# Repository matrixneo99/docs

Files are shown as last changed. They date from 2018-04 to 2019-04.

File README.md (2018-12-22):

# AWTRIX 2.0

After a break of more than half a year the development of ***AWTRIX 2.0** started.
The reason for a complete version jump is relatively simple:
The ESP8266 is very inflexible for such applications. This is partly due to the relatively low memory and RAM. It was simply not possible to add more functions and at the same time guarantee the stability or to keep features like OTA.

***AWTRIX 2.0*** is therefore built in 2 parts:
The ESP8266 as Matrix Driver (AWTRIXController)
And a Java capable host like Windows, MacOS, RaspberryPi, etc. The host takes over the complete logic while the ESP takes over the commands and displays them stubbornly.

***AWTRIX 2.0*** is based on Java 8 and has been trimmed for resource-saving functionality.
(5% CPU Load on a Rpi ZeroW).

Due to the inexhaustible resources I was able to make ***AWTRIX 2.0*** a great user experience. It starts with the simple setup and installation and ends with the intuitive operation. ***AWTRIX 2.0*** is the result of one month of hard work and very good feedback from the community.

Features of ***AWTRIX 2.0***:
- Platform independent
- Control via web interface with responsive Design
- Apps can be added through the integrated Appstore.
- Felxible App management
- Support for Community Apps
- API interfaces like MQTT and REST

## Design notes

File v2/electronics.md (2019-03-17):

# **Electronic**

The electronics can either be soldered to a breadboard or wired "overhung". (PCB may still be available for a small fee in the future)

Soldering directly to the matrix can have fatal consequences, as the flexible PCB and especially the LEDs are extremely heat-sensitive. Leave the cable at the input (DI,5V,GND) and cut off only the plug. If your matrix has an output (DO), you can remove it completely.
Before soldering the socket for the power supply, screw it to the housing with 2 soldered wires.

***Core setp up:***   
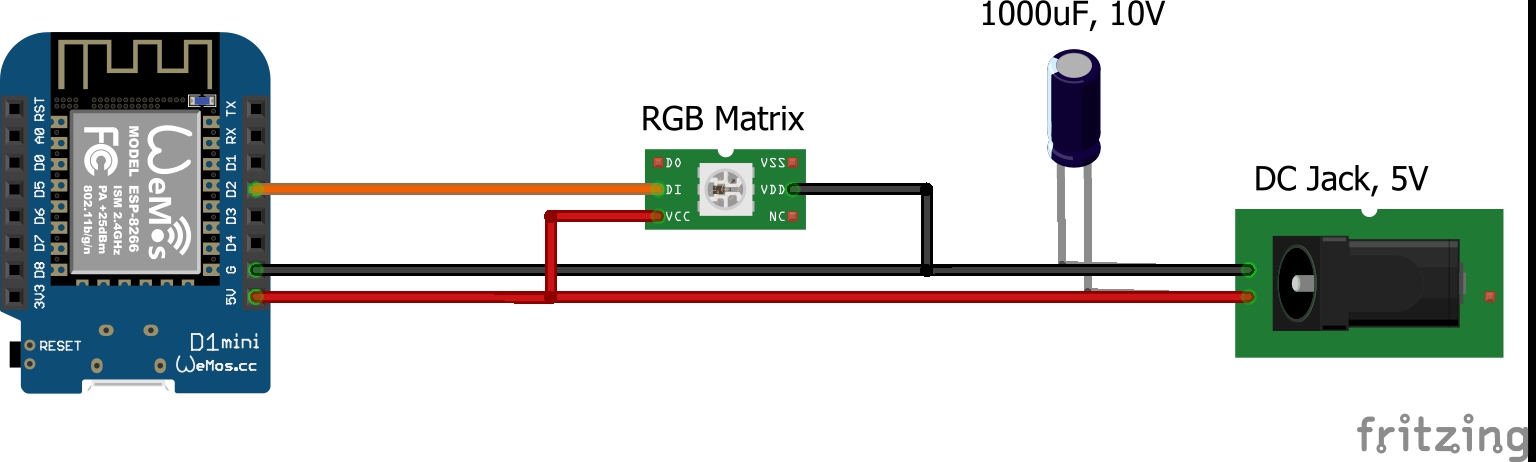
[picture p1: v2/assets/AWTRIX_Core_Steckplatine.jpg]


***Optional LDR setp up:***  
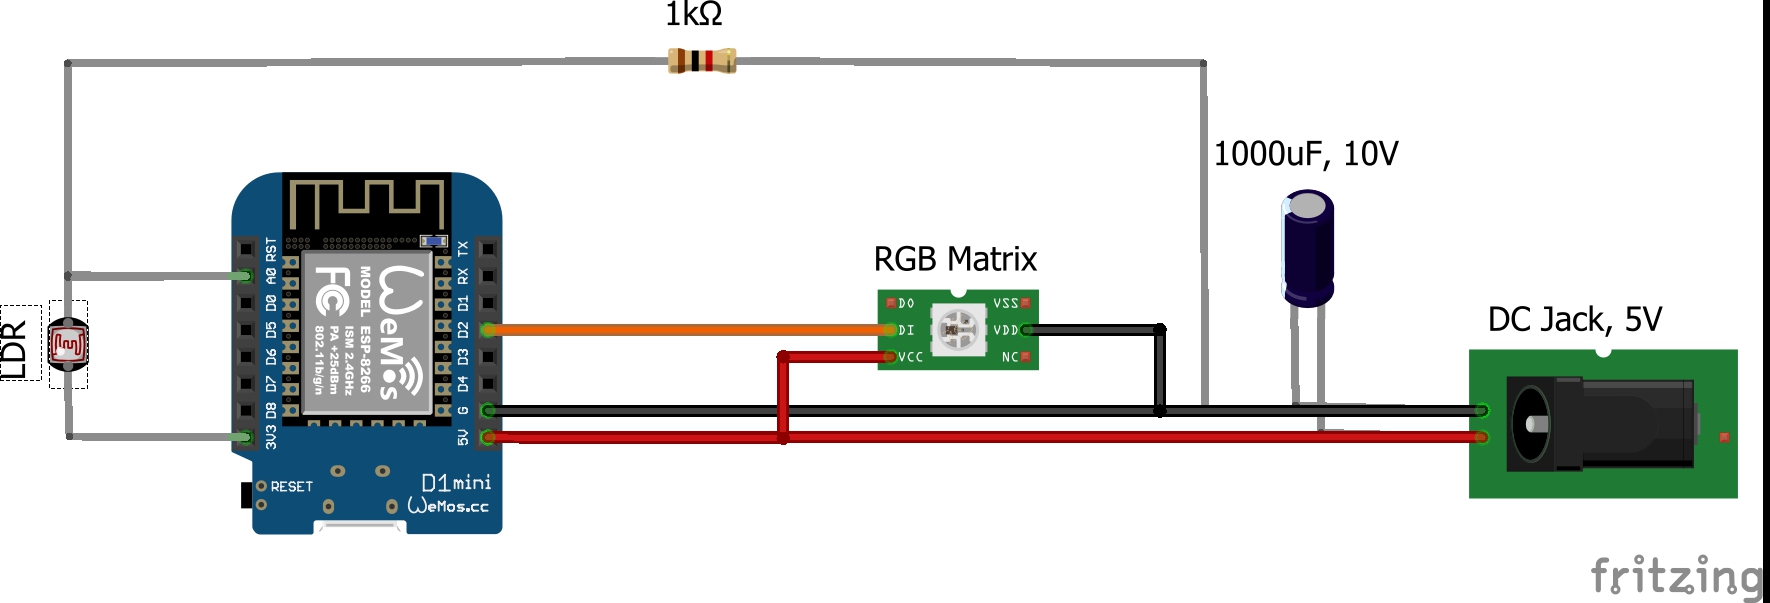
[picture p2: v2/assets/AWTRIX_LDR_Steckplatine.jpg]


***Optional Gesture setp up:***  
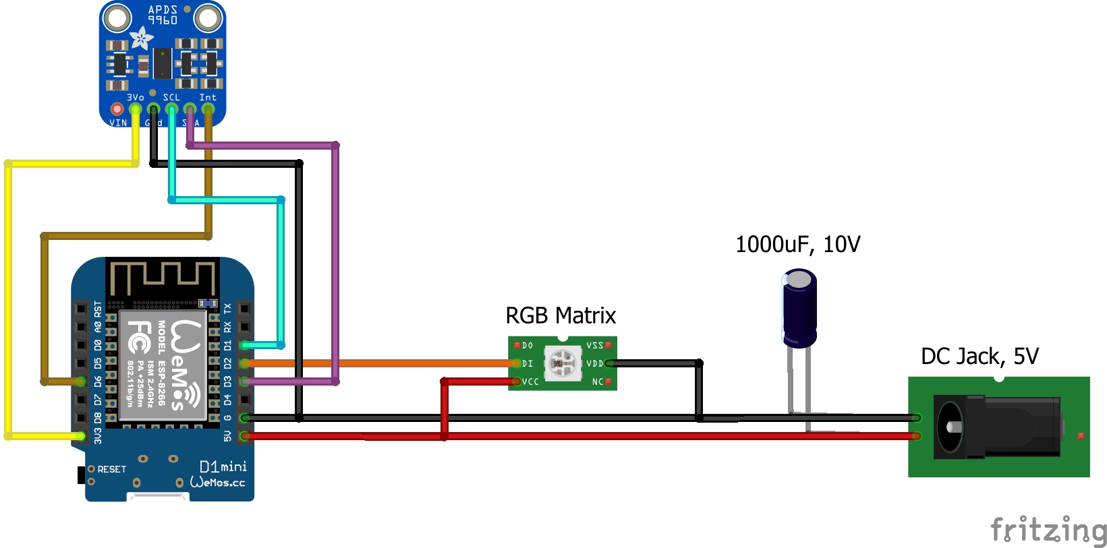
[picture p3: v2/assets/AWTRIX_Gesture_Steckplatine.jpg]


***Gesture control*** 
You can control AWTRIX with Hand gestures (Only switching between Apps for now) with a APDS-9960 Gesture Sensor
Please keep in mind that the Housing is not prepared for mounting this sensor. You will have to do it by your own.
  
!> IMPORTANT: The APDS-9960 can only accept 3.3V!

| Wemos | APDS-9960 | Function |
| --- | --- | --- |
|3.3V|VCC|Power|
|GND|GND|Ground|
|D3|SDA|I2C Data|
|D1|SCL|I2C Clock|
|D6|INT|Interrupt|

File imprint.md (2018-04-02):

# **Housing**

## **3D-Print**

The housing can be created with a 3D printer. The necessary files can be downloaded from Thingyverse.[https://www.thingiverse.com/thing:2791276](https://www.thingiverse.com/thing:2791276)

The 3D objects are already aligned as they should be printed to require as little support material as possible. Please print the **LED grid in black**, otherwise the "pixels" are not clearly separated, as they shine through the material.
**Recommended print settings:**

* 0.2 mm layer resolution

* 20% infill

* Support from the bed

* 45-55 mm/s

## **Assembly**

First of all, glue the 2 parts for the LED Grid together on the inside.
As a diffuser I used high quality and thicker paper - it’s important that you don’t see the fibres when you hold it against bright light like normal printer paper.
Then smear the flat side of the LED grid with glue stick and glue the paper onto it.
this is best done where Awtrix will end up. Due to high temperature and humidity fluctuations, the paper can warp slightly.
Then put the 2 housings parts together and, if necessary, fix it with a little glue. Solder 2 cables to the power jack and screw it to the housing. You can then continue directly with the remaining wiring. the LDR can be plugged through one of the upper 5mm ventilation holes. When everything is ready, place the diffuser facing down and place the LED matrix on top of it, which should fit perfectly in the groove and Press the housing onto the LED Grid. Then turn everything on the back and attach the front frame.

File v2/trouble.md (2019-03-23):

## **Troubleshooting**

### Firmware
If you have trouble to compile the Firmware, try updateing platformio via the terminal  
```platformio update```   

![image alt text](assets/plattformio_update.jpg)  

### Matrix
If your Matrix shows weird Pixel and you cant read it, you have to set the Matrixmode 2 and flash the Firmware again. 
- just uncomment (remove the first two //) 
```//#define MATRIX_MODEV2```

### Jittering display
 
AWTRIX sends the frames to the ESP with an average of 15 FPS (this depends on the current App).
If the Wifi Router does not pass the frames to the ESP in real time, the display jerks. There is no Framebuffer in the ESP firmware.
It is important to keep the network connection as short as possible. If possible, connect the server via network cable and avoid using Wifi repeaters or Powerlan adpater. These can delay the communication.

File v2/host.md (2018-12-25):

AWTRIX 2.0 can run on any platform (Windows, MacOS, Linux), the only requirement is the support of Java8. It is a non-GUI application so you doesnt need an desktop enviroment.   
This Tutorial describes the installation on a Linux machine (in my case a Raspberry ZeroW with Rasbian Lite)

First check if Java is installed  
```java -version```  
  
Otherwise install the latest Java8:  
```sudo apt-get install oracle-java8-jdk```  

Set your timezone: e.g  
``` sudo timedatectl set-timezone Europe/Berlin```  
   
## **Quickstart**
This short example shows how to start the Java application.
Move to the next point for installing on a Linux machine such RaspberryPi

Download the current java  file
[AWTRIX Java application](http://awtrix.blueforcer.de/awtrix.jar)

 and start it via command line or terminal
 ``` sudo java -jar awtrix.jar ```    

!> **sudo** is not always needed. It depends on the folder in wich you want to start the Application. Awtrix need to create new folders and files, so in few cases Awtrix has no write permissions.

Shortly after the start the web interface can be called via http://awtrix_ip:7000.

## **Installing on a Linux machine with Autostart**
```sudo mkdir /usr/local/awtrix```  
```cd /usr/local/awtrix```    
```sudo wget http://awtrix.blueforcer.de/awtrix.jar```

### **Autostart**

Create a file under  **/etc/systemd/system/** with nano or vi. eg.  
```sudo nano /etc/systemd/system/awtrix.service```  
  
Paste the code below in this new file:
```
[Unit]
Description = AWTRIX Service
After network.target = awtrix.service

[Service]
Type = forking
WorkingDirectory =/usr/local/awtrix
ExecStart = /usr/local/bin/awtrix.sh start
ExecStop = /usr/local/bin/awtrix.sh stop
ExecReload = /usr/local/bin/awtrix.sh reload

[Install]
WantedBy=multi-user.target
```

Create a new file under ***/usr/local/bin/*** eg.   
```sudo nano /usr/local/bin/awtrix.sh```  
  
And paste this code
```
#!/bin/sh
SERVICE_NAME=awtrix
PATH_TO_JAR=/usr/local/awtrix/awtrix.jar
PID_PATH_NAME=/tmp/awtrix-pid
case $1 in
    start)
        echo "Starting $SERVICE_NAME ..."
        if [ ! -f $PID_PATH_NAME ]; then
            sudo nohup java -jar $PATH_TO_JAR /tmp 2>> /dev/null >> /dev/null &
                        echo $! > $PID_PATH_NAME
            echo "$SERVICE_NAME started ..."
        else
            echo "$SERVICE_NAME is already running ..."
        fi
    ;;
    stop)
        if [ -f $PID_PATH_NAME ]; then
            PID=$(cat $PID_PATH_NAME);
            echo "$SERVICE_NAME stoping ..."
            kill $PID;
            echo "$SERVICE_NAME stopped ..."
            rm $PID_PATH_NAME
        else
            echo "$SERVICE_NAME is not running ..."
        fi
    ;;
    restart)
        if [ -f $PID_PATH_NAME ]; then
            PID=$(cat $PID_PATH_NAME);
            echo "$SERVICE_NAME stopping ...";
            kill $PID;
            echo "$SERVICE_NAME stopped ...";
            rm $PID_PATH_NAME
            echo "$SERVICE_NAME starting ..."
            sudo nohup java -jar $PATH_TO_JAR /tmp 2>> /dev/null >> /dev/null &
                        echo $! > $PID_PATH_NAME
            echo "$SERVICE_NAME started ..."
        else
            echo "$SERVICE_NAME is not running ..."
        fi
    ;;
esac
```

save the file and give execution permisions

``` sudo chmod +x /usr/local/bin/awtrix.sh``` 

Test that it runs with:  
```sudo /usr/local/bin/./awtrix.sh start```     
Test that it stops with:   
```sudo /usr/local/bin/./awtrix.sh stop```     
Test that it restarts with:  
```sudo /usr/local/bin/./awtrix.sh restart```     

If everything is working, enable the service with the command

```sudo systemctl enable awtrix```  

To run awtrix  
```sudo systemctl start awtrix.service ```   
To stop awtrix   
```sudo systemctl stop awtrix.service```   
To restart awtrix   
```sudo systemctl restart awtrix.service``` 

## **Docker**
**(Only for x64 platforms!)**  

https://hub.docker.com/r/o0shojo0o/awtrix

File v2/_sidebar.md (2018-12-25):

* [Home](v2/)

* Hardware
    * [Partslist](v2/partslist)
    * [Electronics](v2/electronics)
    * [Housing](v2/housing)

* Software
    * [AWTRIX Controller](v2/firmware)
    * [AWTRIX Host](v2/host)

* Usage
    * [Webinterface](v2/web)
    * [Appsetup](v2/appsetup)
    * [API](v2/api)

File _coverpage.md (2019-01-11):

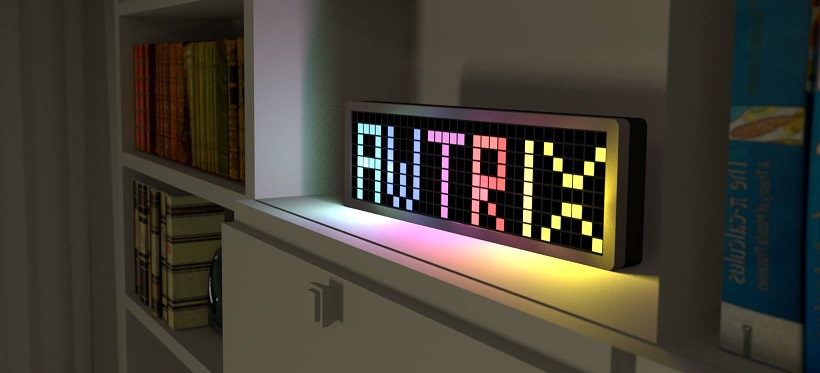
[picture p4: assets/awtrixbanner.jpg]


# AWTRIX 

> Official (BETA) documentation

* Simple to build
* Lots of functions
* Opensource

[Github](https://github.com/awtrix/awtrix)
[Getting Started](v1/README)

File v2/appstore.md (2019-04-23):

## **Appstore**   
AWTRIX has its own appstore.  
Here all tested apps are provided and can be downloaded or updated.  
After a download you find this app in MyApps.  

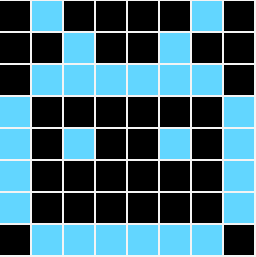
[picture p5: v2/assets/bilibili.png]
 **Bilibili**  
Shows count of fans at Bilibili.  
https://space.bilibili.com  

 **Sunrise**  
Shows sunset and sunrise times for a given location.  
https://www.sunrise-sunset.org 

 **GameOfLife**  
Conway's Game of Life  
Internal App

 **LookingEyes**  
Just some looking eyes :)   
Internal App

 **Matrix**  
Shows the popular Matrix animation.  
Internal App

 **PeopleInSpace**  
Shows how many people are in space right now.     
https://www.howmanypeopleareinspacerightnow.com/ 

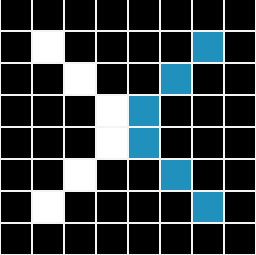
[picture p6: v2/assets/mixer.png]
 **mixer**  
Shows your mixer subscriber count or your live viewers while youre streaming.     
https://mixer.com/  

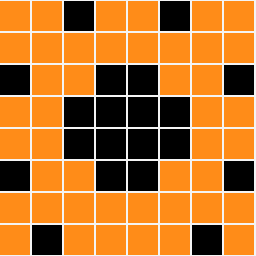
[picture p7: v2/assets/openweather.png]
 **OpenWeather**  
Shows the current temperature of your location.    
https://openweathermap.org/  

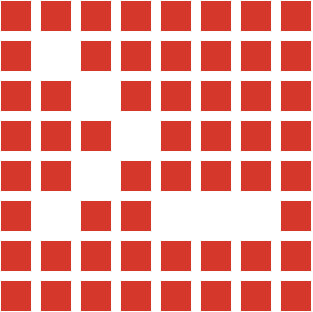
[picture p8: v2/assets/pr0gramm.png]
 **pr0gramm**  
Show the lenght of your Benis.     
https://pr0gramm.com  

 **MinecraftServer**  
Shows the player count of a Minecraft Server.  
Only appears if the server is online.  
https://www.minecraft.net  

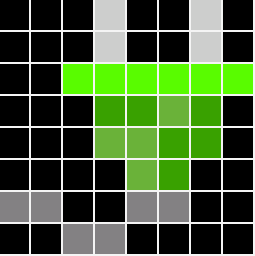
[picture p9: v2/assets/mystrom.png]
 **mystrom**  
Shows the state and power consumption of your MyStrom SmartPlug.  
https://mystrom.com/  

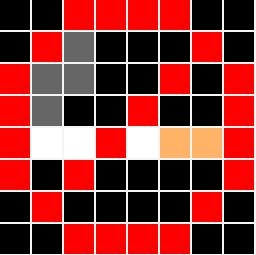
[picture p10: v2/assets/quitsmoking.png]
 **QuitSmoking**  
Shows the days how long you don't smoke anymore.  
Internal App  

 **TronalDump**  
Shows the dumbest things Donald Trump has ever said.  
https://tronalddump.io  

 **Countdown**  
Shows the remaining days from now to a target date.  
Internal App  

 **Crypto**  
Shows prices for any cryptocurrency. Set your desired Coin and your currency.   
https://www.cryptonator.com/api    

 **facebook**  
Shows your Facebooksite likes count.   
www.facebook.com  

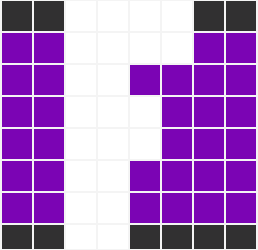
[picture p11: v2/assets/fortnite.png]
 **fortnite**  
Shows your Kills, Wins, Wins% and K/D.   
https://www.epicgames.com/fortnite/de/home  

 **gas**  
Zeigt dir die Spritpreise in deiner Naehe an.(Tankerkoenig API)  
www.tankerkoenig.de  

 **instagram**  
Shows your Instagram follower count.   
www.instagram.com  

 **matomo**  
Shows you the visitors of the transferred Matomo instance who were online during the given time period.  
http://matomo.org  

 **moon**  
Get Today's Moon Phase with current viewing information.  
Internal App  

 **news**  
This app provides live top and breaking headlines for your country.  
http://newsapi.org  

 **octoprint**  
Shows the percentage of progress and remaining time of OctoPrint printing.  
http://octoprint.org  

 **overwatch**  
Shows your current Skillranking.  
http://playoverwatch.com  

 **pinterest**  
Shows your pinterest follower count.  
www.pinterest.com  

 **pm**  
Shows the atmospheric particulate matter (PM).  
https://openaq.org/#/map

 **speedtest**  
Measures the time between the Frames.  
Internal App  

 **twitch**  
Shows your Twitch subscriber count or your live viewers while you are streaming.  
www.twitch.tv  

 **twitter**  
Shows your Twitter Follower count.  
http://twitter.com  

 **weather**  
Shows the current temperature of your location.  
www.apixu.com  

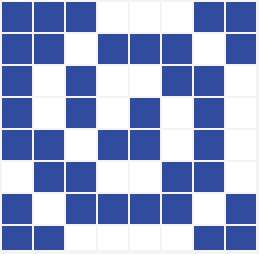
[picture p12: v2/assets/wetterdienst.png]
 **wetterdienst**    
Displays weather-warnings of Deutscher Wetterdienst.  
Only appears if there is at least one warning.  
https://www.dwd.de/DE/leistungen/opendata/help/warnungen/cap_warncellids_csv.csv/

 **youtube**  
Shows your Youtube subscriber count.  
www.youtube.com

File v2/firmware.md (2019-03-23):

## **IDE**

Platform.IO is used to edit and upload the firmware.
The underlying IDE (Atom, Visual Studio Code) does not matter.
However, this manual is based on Visual Studio Code(VSC) and may need to be adapted.
The installation of the IDE is described in the following link:
[https://platformio.org/platformio-ide](https://platformio.org/platformio-ide)

## **Download and open firmware**

The firmware can be downloaded from github as a ZIP file
[https://github.com/awtrix/AWTRIX2.0-Controller](https://github.com/awtrix/AWTRIX2.0-Controller)
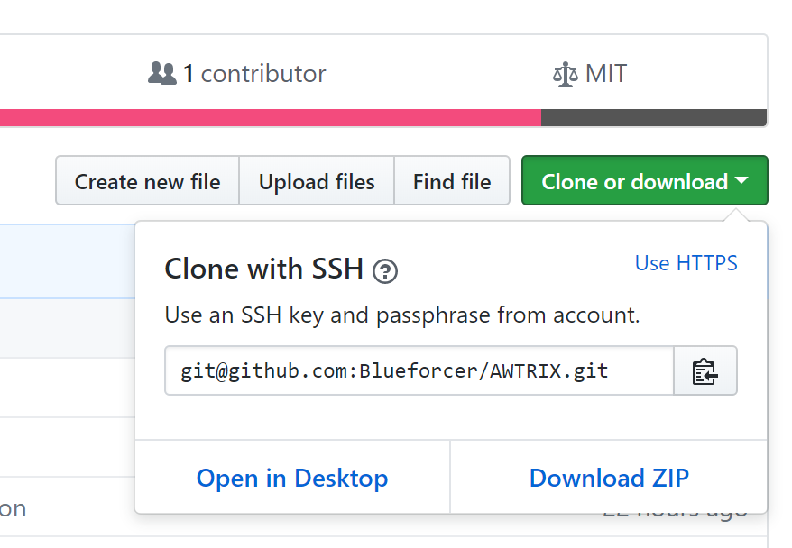
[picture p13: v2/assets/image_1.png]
image alt text


Unzip the ZIP file with a suitable unpacker and open the folder in Visual Studio Code.

## **Setup**

Before flashing the Firmware, open **awtrix-conf.h** and edit your wifi credentials and set the IP from the Server wich should run the serverapplication.  If you using a LDR for automatic brightness control, you also need to modify the LDR section. if not, just ignore it.
If you want to use Gesture Control with the APDS-9960 Sensor, Set GESTURE to true  
image alt text

 Then simply flash the firmware. In VSC, this is done in the blue line at the bottom of the window:  

image alt text

## **OTA(Over the air) Update**
AWTRIXController supports over-the-air updates. PlatformIO Terminal:  
(Replace IP of the AWTRIX controller)  
```platformio run -t upload --upload-port 192.168.178.96```
Please note: First OTA only works after ESP reset  

![image alt text](assets/OTA_update_AWTRIXController.jpg)

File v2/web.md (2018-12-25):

## **Webinterface**

In order to make the operation as simple as possible for everyone, the complete operation takes place via a web interface.
The standard port is 7000.

Here you can manage all your settings, manage your apps and download new one.

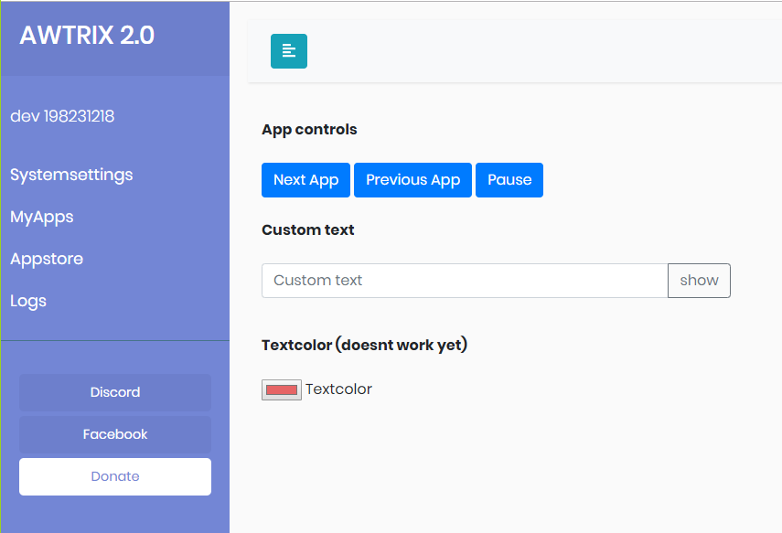
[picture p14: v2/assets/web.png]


## **Systemsettings**
Here you will find all relevant settings concerning the operation of Awtrix. Like e.g. brightness, text color or connection settings

## **MyApps**
The administration of all your apps takes place here.
Here you can configure or delete your apps  
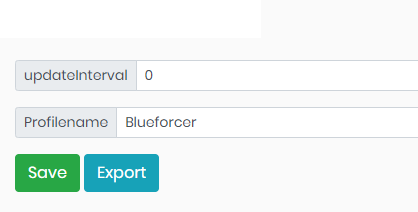
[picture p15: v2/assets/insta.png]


Every App has its own updateInterval. If it is set to 0, it means that this app together with the other apps will be updated after a global period. (Systemsettings->updateInterval).   
This setting is sufficient for most apps not to exhaust the API quota.  
However, if desired, the interval at which the app fetches new data can be forced. Just enter a timespan in seconds (minimum 10s). 

## **Appstore**
Awtrix has its own appstore.
Here all tested apps are provided and can be downloaded or updated.
After a download you find this app in MyApps. New apps are only displayed if they have been set up.

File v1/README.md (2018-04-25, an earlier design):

# AWTRIX

Welcome to my first open source project. This documentation is maintained to the best of my knowledge and belief. However, it can of course happen that errors creep in. If you have any problems or questions, please feel free to contact the Facebook group. They'll be happy to help you.  

Special Thanks to my friend Quentin Daems for this review! [Subscribe](https://www.youtube.com/channel/UCM8iZUKxIHGmAaRcQ_aTYfA) his Channel for more Weekend Makes!  
<iframe width="560" height="315" src="https://www.youtube.com/embed/PjhV3jEGNtc?rel=0" frameborder="0" allow="autoplay; encrypted-media" allowfullscreen></iframe>  

Here are a few links:  
  
[Release Page](https://awtrix.github.io)  
[Facebook Group](https://www.facebook.com/groups/126493104851075/)  
[Buy me a coffee or a case of beer :-)](https://www.paypal.com/donate/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)  

AWTRIX is a smart WiFi-capable clock based on an ESP8266.

- Time and date via NTP server
- Current weather via Openweathermap
- Simulation of a virtual "pet" with different emotions 
- Game of Life 
- Youtube Counter
- Facebook Counter
- Twitter Counter
- DHT Senor reading
- Fire simulation

more functions: 
- Control and configuration via BLYNK, MQTT, UDP or Android App
- Automatic brightness control via LDR
- easy Firmware update via WiFi or Web or Autoupdate

The case is designed in Fusion360 and printed in 3D.
You can get the STL-Files from Thingiverse:
https://www.thingiverse.com/thing:2791276

Facebook-Group:
https://www.facebook.com/groups/126493104851075/

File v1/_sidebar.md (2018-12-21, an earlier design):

* [Home](v1/)
* [How it works](v1/description)
* [API](v1/api)
* [Android App](v1/app)
* [Blynk](v1/blynk)
* [Current Blynk Layout](v1/actual_blynk)

* Hardware
    * [Partslist](v1/partslist)
    * [Electronics](v1/electronics)
    * [Housing](v1/housing)

* Software
    * [Firmware](v1/firmware)
    * [First Configuration](v1/config)
    * [Upload to ESP8266](v1/upload)
    * [First start](v1/first_start)
    * [Update](v1/update)

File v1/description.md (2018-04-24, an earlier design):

## How it works

AWTRIX includes a variety of apps that can display different functions. All activated apps are looped one after the other. The adjustable time in which an app is displayed is the same for each app. Each function can be activated in the settings.json.

**Sleep Mode**

the sleep mode can be activated by setting a time period via blynk or the Settings.json.
During this period Awtrix only displays the time (strongly darkened). 

**Rainbow mode**

When Rainbow mode is on, the set text color is ignored and each text is displayed in rainbow colors.

**Here is an explanation of how each officially available app works:**

**TimeApp**

Displays the current time and date rotationally. The time is synchronized with a time server (NTP) every 3 minutes. The BIG_TIME setting changes the type of display.

In addition, the current day of the week can be displayed at the bottom of the screen. Here 7 strokes are drawn which stand for all 7 weekdays (Monday-Sunday). The current day of the week is displayed in white, while the remaining days are displayed in gray. AWTRIX supports the automatic summer and winter time changeover.

**WeatherApp**

shows the current weather with an icon. Furthermore, the current temperature of the configured location is displayed. The data is downloaded from Openweatermap.

**Pet**

Shows 2 eyes that look and blink randomly in all directions. The displayed emotion changes via the setting PET_MOOD.

**GOL**  
Represents the game of the mathematician [John Horton Conway](https://de.wikipedia.org/wiki/John_Horton_Conway).  
Rules of the game: [https://de.wikipedia.org/wiki/Conways_game_of_life](https://de.wikipedia.org/wiki/Conways_game_of_life)

**FacebookApp**

shows the current likes of a Facebook page.

**YoutubeApp**

shows the number of subscribers to a YouTube channel.

**TwitterApp**

shows the number of followers of a Twitter profile.

**FireApp**

simulates a fire source

**DHTApp**

displays the values of a DHT11 or DHT22 sensor. The display changes between temperature and humidity each time the app is restarted.

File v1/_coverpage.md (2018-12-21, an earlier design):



# AWTRIX <small>0.7</small>

> Official (BETA) documentation

* Simple to build
* Lots of functions
* Opensource

[GitHub](https://github.com/awtrix/awtrix)
[V1.0](README)
[V2.0](README)

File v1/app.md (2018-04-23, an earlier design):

## Android App

I am proud to introduce Awtrix's own app. This makes it a lot easier to configure Awtrix.
The app is still in beta but many features are already covered. The app should be self-explanatory. Through the menu in the upper right corner you can open the settings to configure Awtrix and start the games.
You can download the App from the Android [PlayStore](https://play.google.com/store/apps/details?id=de.awtrix). 
An iOS app may follow in the future.

**Please note:**
The app communicates with Awtrix via UDP. 
The User Datagram Protocol (UDP) is the simplest form of IP data transmission. Data is simply chased off in one direction. UPD does not take care that the data is transmitted without errors. It doesn't even guarantee the arrival of the packages.
This form of data transmission is the fastest and simplest but the ESP8266 is much less busy than with TCP.

Anyway, I try to confirm receipt by replying and send it again if necessary, but now and then it can be that the data is lost.
In addition, it may be that other Awtrix applications have problems downloading their data due to a packet flood (e.g. due to a fast change of the brightness). But  after the next Apploop everything should work again.

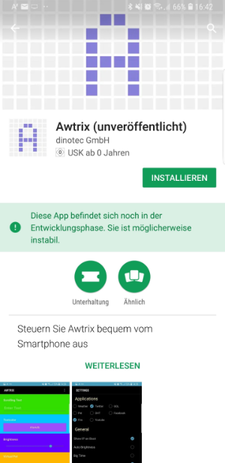
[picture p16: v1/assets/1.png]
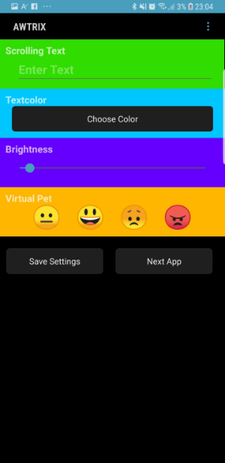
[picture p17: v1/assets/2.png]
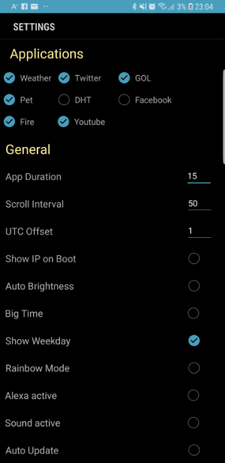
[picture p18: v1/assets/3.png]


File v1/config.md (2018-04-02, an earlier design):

## **AWTRIX Configuration**
The configuration consists  2 parts. 
On the one hand the settings for the display settings and on the other hand the configuration of the API keys of the individual apps. Both files are located in the root directory and must be renamed and copied to the folder "data" before uploading.  

**Settings**    
The settings are listed in "settings.example.json". The file itself also contains the explanations of the individual settings. Before uploading the file, it is important to rename it to "settings.json" and copy it to the "data" folder.

**Config**  
The configuration is adapted in "config.example.json".  Before uploading the file, it is important to rename it to "config.json" and copy it to the "data" folder.  

**API Keys etc**

Openweathermap API (required for weather display):
All necessary data can be obtained with a free account at http://openweathermap.org/appid

the OWM Location (City-ID) can be taken from the link after the weather search of the location (e.g. http://openweathermap.org/city/2874230)

Youtube API (required for the Youtube app)
Follow these instructions (last step is not necessary)
https://www.vimp.com/de/web/faq-medien/items/wie-erstelle-ich-einen-youtube-api-key.html

Facebook API (required for the Facebook app)    
The URL is composed as follows: 
/AAA?access_token=BBB|CCC&fields=fan_count  
and consists of  
AAA = Facebook Page ID or Name  
BBB = App ID    
CCC = App Secret    
A Facebook App must be created for this data:   
https://developers.facebook.com/    

That's how you get the fingerprint:
https://github.com/gbrault/esp8266-Arduino/blob/master/doc/esp8266wifi/client-secure-examples.md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

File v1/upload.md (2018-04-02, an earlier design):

## **Upload to ESP8266**

After all settings are done, the firmware can be uploaded via USB:
In VSC, this is done in the blue line at the bottom of the window:  

image alt text

Then the settings.json and the config.json must be loaded into the flash memory (SPIFFS).  Check that both json files with the correct name are in the folder "data" and run

> **platformio run -t uploadfs **

This is done via the Terminal. The Terminal can be started via the rightmost icon.

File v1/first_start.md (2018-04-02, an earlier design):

## **First start**

After the firmware has been successfully flashed to the ESP8266, Awtrix starts a WiFi access point. "AP" is displayed on Awtrix. Use your WLAN-enabled device to search for the open network "AWTRIX" and connect. Then open a web browser and type in the address bar
**192.168.4.1**
There you have the possibility to connect AWTRIX with your own WiFi. An Internet connection is required for AWTRIX.

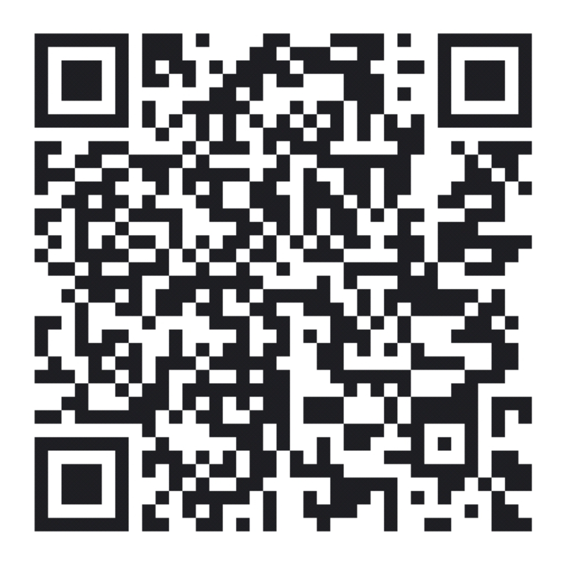
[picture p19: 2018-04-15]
v2/assets/blynk.jpg

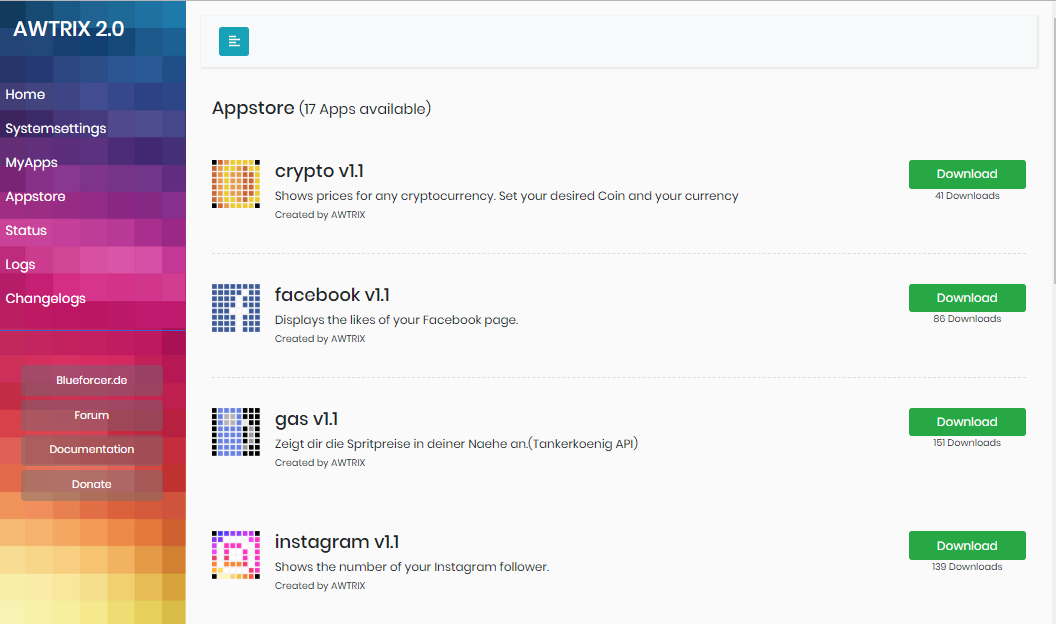
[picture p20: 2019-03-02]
v2/assets/appstore.PNG

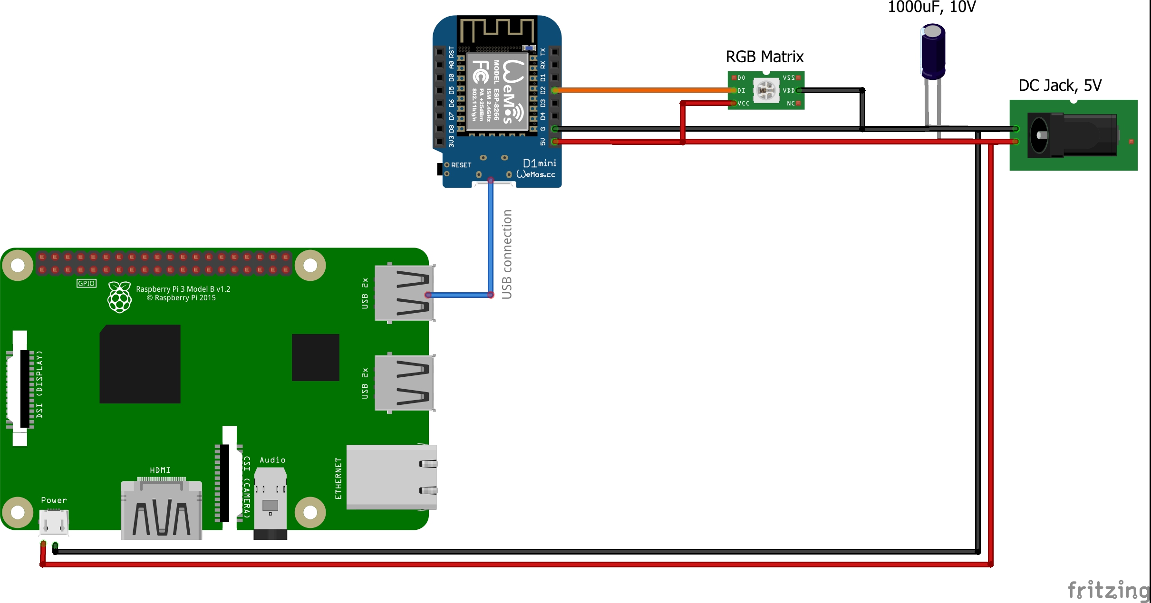
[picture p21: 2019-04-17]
v2/assets/AWTRIX_raspi_V1_Steckplatine.jpg

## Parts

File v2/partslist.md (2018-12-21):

## **Partslist**    

[Wemos D1 Mini (ESP-12E)](https://goo.gl/TVk7h7)

[8x32 WS2812B RGB Matrix](https://goo.gl/Cjq4FA)

[power supply (>4A)](https://goo.gl/QLydM3) 

[DC socket](https://goo.gl/j4Xov7)

[1000uF 10V 105C Capacitor](https://goo.gl/v87Fzt)

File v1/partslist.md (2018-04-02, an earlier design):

## **Partslist**    

[Wemos D1 Mini (ESP-12E)](https://www.amazon.de/AZDelivery-D1-Mini-Entwicklungsboard-kompatibel/dp/B01N9RXGHY/)

[8x32 WS2812B RGB Matrix](https://www.ebay.de/itm/8-32-WS2812B-Digital-Flexibler-Panel-Pixel-Bildschirm-Adressierbar-einzeln-DE/)

[power supply (>4A)](https://www.amazon.de/GreenICE-Netzteil-Transformator-Adaptor-LED-Streifen/dp/B01HZGRUYA/) 
not sure about the plug so optionally order the DC Plug below. I use my own for this. But you can use every 5V supply with at least 4A.  

[DC socket](https://www.amazon.de/gp/product/B000M0MP2E/)

[DC plug (optional)](https://www.amazon.de/gp/product/B000L0ZOMI/)

[LDR GL5528(optional)](https://www.amazon.de/Qualit%C3%A4t-GL5516-Lichtabh%C3%A4ngige-Widerstand-Fotowiderstand/dp/B00NXW9WZ6/)

[Piezo Buzzer (optional)](https://www.amazon.de/gp/product/B00J3PBAN4)

[1000uF 10V 105C Capacitor](https://www.amazon.de/1000uF-RADIAL-KONDENSATOR-10x16mm-Capacitor/dp/B00QX0IH7E/)

1K ohm Resistor for LDR & 100ohm resistor for buzzer

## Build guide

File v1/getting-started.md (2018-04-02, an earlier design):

# Getting Started

This is how you set up Awtrix.

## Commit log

2019-03-02 fortnite und wetterdienst icon
2019-03-17 Update in schematics for Gesture, DFMini, LDR and CORE
    [AWTRIX_Core.fzz, AWTRIX_DFMini.fzz, AWTRIX_Gesture.fzz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]
2019-03-17 Added separate schematics for Core, LDR and Gesture
2019-03-22 AWTRIX Nodes
    [AWTRIX_Node.fzz]
2019-04-17 Raspberry Pi USB Connection
2019-04-18 Raspberry Pi USB Connection
    Raspberry Pi USB Connection
    [AWTRIX_raspi_V1.fzz]
2019-04-18 Raspberry Pi GPIO Connection
    Raspberry Pi GPIO Connection
    [AWTRIX_raspi_V2.fzz]
